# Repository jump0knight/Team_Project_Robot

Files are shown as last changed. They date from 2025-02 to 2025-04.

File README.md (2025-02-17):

# Robot Dog Project

Welcome to the **Robot Dog** project! This repository contains the design files and documentation for our ongoing team project, where we are creating a 3D-printed robot dog. We are integrating various components for functionality, such as sensors, motors, and body connections.

## Project Overview

The goal of this project is to design and build a **robot dog** capable of performing a range of tasks. Our team is working on several modules, including:

- **Body Structure**
- **Leg Connections**
- **Servo Motor Controls**
- **Sensor Integrations**

## Team Contributions

### Hasinu Ravishka
- Designed the **lower leg components** and integrated **servo motor mechanisms**, ensuring precise control over the robot's locomotion.
- Delivered key **mechanical designs** for the leg system, optimizing both **functionality** and **stability**.

### YanSheng Zhao
- Designed and sent the **Shoulder 3D Print**.
- Created and shared the **Wing 3D Print**, which plays a key role in enhancing the robot's **stability** and **movement**.

### Vladimir Galichyan
- Designed and shared the **Top Mount for Body-Sensor Connection** (STL files).
- Contributed to the overall **body** and **sensor** plots design, ensuring proper alignment for seamless connections between components.

### MingYu Xia
- Designed the **Leg-Connect** (now renamed to **Robot-Dog-Connection**), facilitating the connection between the leg components and the robot's body.
- Contributed to the **renaming** of the leg connection part for clarity and consistency.

## 3D Models and Design Files

Here, you will find various **STL** files for the robot's parts, designed for 3D printing:

- **Top Mount (Body-Sensor Connection)** – Essential for connecting the body and sensor components.
- **Shoulder 3D Print** – Part of the robot’s limb system, enabling movement and articulation.
- **Wing 3D Print** – Contributes to the robot's **stability** and overall **movement control**.
- **Lower Leg Design** – Includes 3D-printed parts for the lower leg, as well as **servo motor placement**.
- **Robot-Dog-Connection** – The connection mechanism between the robot's legs and body.

## How to Use

### Requirements:
- A **3D printer** capable of printing the provided **STL files**.
- A **servo motor** for controlling movement.
- A **compatible sensor** for integration with the robot's body.

### Steps:
1. **Download** the required STL files from this repository.
2. Use a **3D printer** to print the parts.
3. **Assemble** the robot following the provided designs and instructions for each module.
4. **Integrate** the motors and sensors as needed to bring the robot to life.

## Contributors
- **YanSheng Zhao**
- **Hasinu Ravishka**
- **Vladimir Galichyan**
- **MingYu Xia**

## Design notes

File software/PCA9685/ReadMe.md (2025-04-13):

# How to use these Library

## -------environment-------  Raspberry PI PICO ------ Mico Python

## First. Connect the PCA9685 

SCL - GPIO3

SDA - GPIO2

## Second. Put These three files in Pico



## Then. We make a main file to run the leg

```python
import leg
import math , time

print(leg.legleft1_A(90,160,120))
print(leg.legleft2_A(90,160,120))
print(leg.legright1_A(90,160,120))
print(leg.legright2_A(90,160,120))
```

## Final run  it you will see this data back . So it working.



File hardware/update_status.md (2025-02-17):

/******   2025 2 4  *******/

Create the task :

YanSheng Zhao -- shoulder and Wings design.

Hasinu Ravishka -- lower leg and servo motor design.

MingYu Xia -- leg-connect and sensor plots design.

Vladimir Galichyan -- body and sensor plots design.

/******************************************************/

/******   2025 2 11  *******/

/****** YanSheng Zhao ******/

Send the shoulder 3D print.

/****** Hasinu Ravishka******/

I have send lower leg and servo motor design.

/****** MingYu Xia******/

Send the leg-connect 3D print.

/******************************************************/

/******   2025 2 14  *******/

/****** YanSheng Zhao ******/

Send the Wing 3D print.

/****** MingYu  Xia ******/

I change the name from leg-connect to Robot-Dog-Connection

/****** Vladimir Galichyan ******/

Send top mount for body robot dog body-sensor connect stl

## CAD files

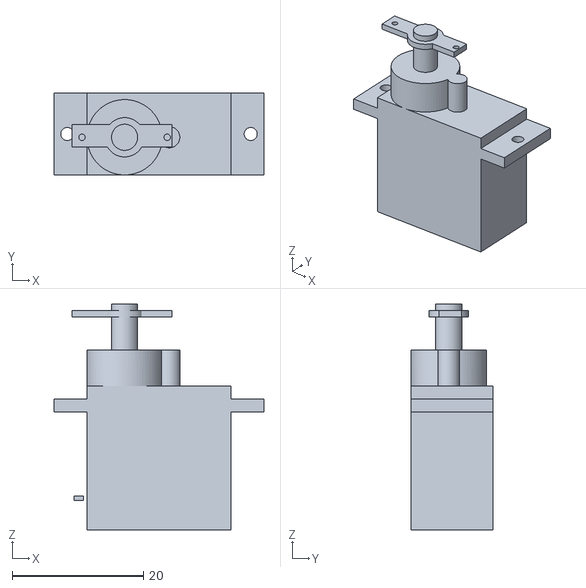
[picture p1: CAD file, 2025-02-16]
hardware/Robot-Dog- Servo.stl
32.0 x 12.5 x 34.5

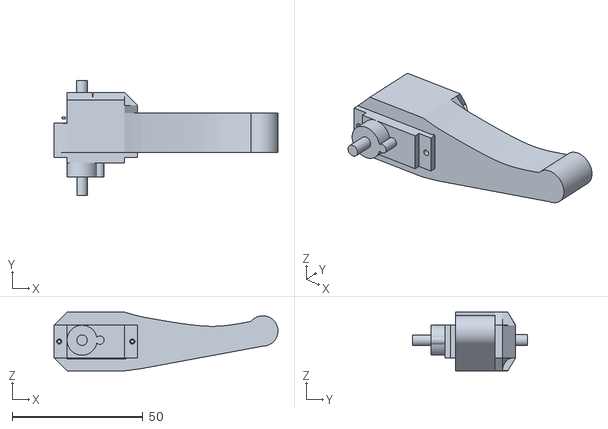
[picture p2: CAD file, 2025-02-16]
hardware/Robot-Dog-LowerLeg.stl
85.8 x 44.0 x 22.5

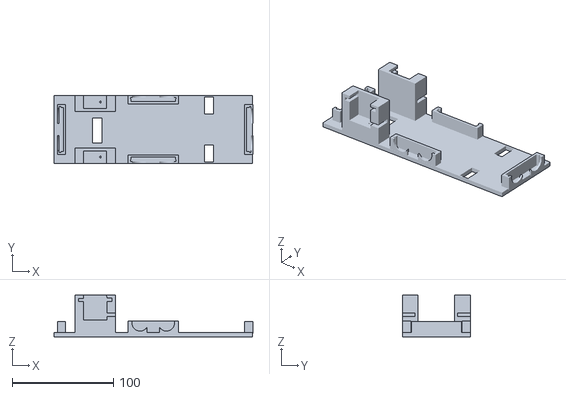
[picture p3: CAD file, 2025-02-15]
hardware/Robot-Dog-body-sensor connect.stl
196.7 x 67.3 x 41.1

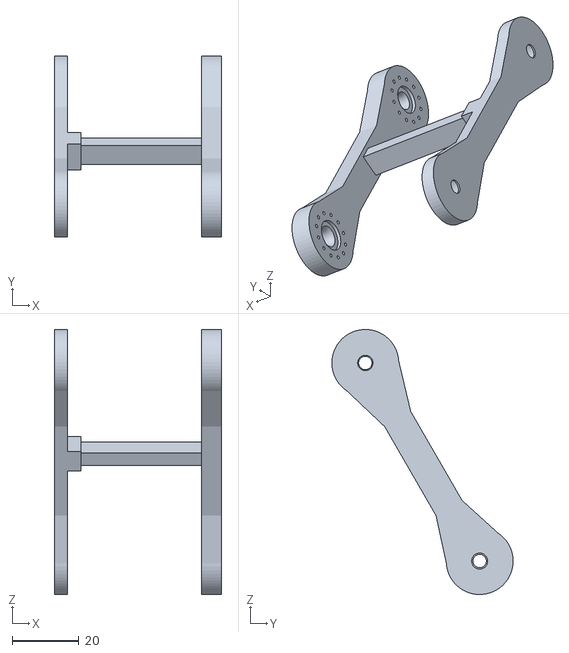
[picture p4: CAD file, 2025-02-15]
hardware/Robot-Dog-Connection.stl
50.0 x 54.2 x 79.1

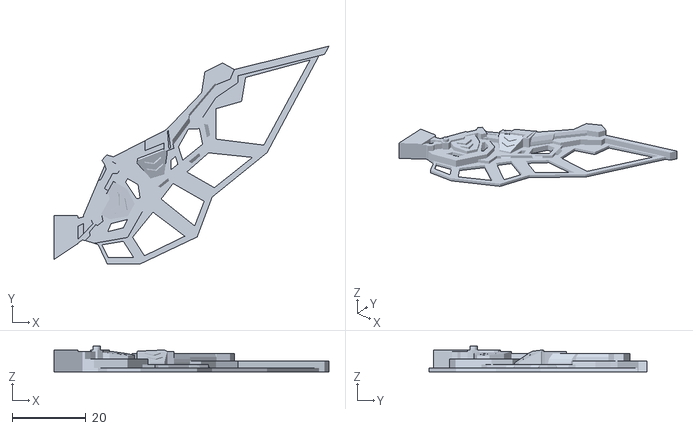
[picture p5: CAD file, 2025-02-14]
hardware/Robot-Dog-wing.stl
74.8 x 59.2 x 7.00

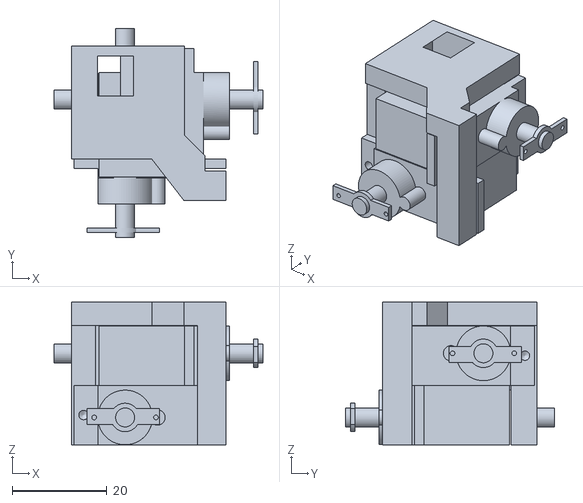
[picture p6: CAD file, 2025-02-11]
hardware/Robot-Dog-Shoulder.stl
44.0 x 44.0 x 30.0

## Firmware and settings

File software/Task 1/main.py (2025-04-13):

import machine
import time
import uasyncio as asyncio
import leg
import math
from machine import Pin, time_pulse_us

# UART 初始化
uart = machine.UART(1, baudrate=115200, tx=machine.Pin(4), rx=machine.Pin(5))

# 帧常量
HEADER1 = 0xFF
HEADER2 = 0xAA
FOOTER1 = 0xBF
FOOTER2 = 0xC0

# 全局状态
current_mode = "stop"

# ------------------------------
# 超声波传感器配置（根据实际接线修改引脚）
sensor1 = {
    'trig': Pin(16, Pin.OUT),
    'echo': Pin(17, Pin.IN),
    'name': 'Ultrasonic1'
}

sensor2 = {
    'trig': Pin(14, Pin.OUT),
    'echo': Pin(15, Pin.IN),
    'name': 'Ultrasonic2'
}

# ------------------------------
# 异步读取超声波传感器数据
async def read_ultrasonic(sensor):
    trig_pin = sensor['trig']
    echo_pin = sensor['echo']
    name = sensor['name']
    while True:
        # 发出触发脉冲
        trig_pin.value(0)
        time.sleep_us(2)
        trig_pin.value(1)
        time.sleep_us(10)
        trig_pin.value(0)
        try:
            pulse_time = time_pulse_us(echo_pin, 1, 1000000)
            # 计算距离（cm）：距离 = (脉冲时长/2) / 29.1
            distance = (pulse_time / 2) / 29.1
            if distance < 500:
                print(f"{name} Distance: {distance:.2f} cm")
        except OSError as e:
            print(f"{name} Ultrasonic Read Error:", e)
        await asyncio.sleep(0.5)

# ---------------- 参数 ----------------
step_period = 1000
base_hip = 160
base_knee = 120
base_shoulder = 90
amplitude_knee = 10
phase_offset_left1 = 0
phase_offset_left2 = math.pi
phase_offset_right1 = math.pi
phase_offset_right2 = 0

# ---------------- 运动函数 ----------------
def move_legs(amp_l, amp_r, dir_l=True, dir_r=True):
    current_time = time.ticks_ms()
    cycle_time = (current_time % step_period) / step_period
    phase = cycle_time * 2 * math.pi

    sign_l = 1 if dir_l else -1
    hip_left1 = base_hip + sign_l * amp_l * math.cos(phase + phase_offset_left1)
    knee_left1 = base_knee + amplitude_knee * math.sin(phase + phase_offset_left1)
    hip_left2 = base_hip + sign_l * amp_l * math.cos(phase + phase_offset_left2)
    knee_left2 = base_knee + amplitude_knee * math.sin(phase + phase_offset_left2)

    sign_r = 1 if dir_r else -1
    hip_right1 = base_hip + sign_r * amp_r * math.cos(phase + phase_offset_right1)
    knee_right1 = base_knee + amplitude_knee * math.sin(phase + phase_offset_right1)
    hip_right2 = base_hip + sign_r * amp_r * math.cos(phase + phase_offset_right2)
    knee_right2 = base_knee + amplitude_knee * math.sin(phase + phase_offset_right2)

    leg.legleft1_A(base_shoulder, hip_left1, knee_left1)
    leg.legleft2_A(base_shoulder, hip_left2, knee_left2)
    leg.legright1_A(base_shoulder, hip_right1, knee_right1)
    leg.legright2_A(base_shoulder, hip_right2, knee_right2)

def walk_forward():
    move_legs(10, 10, dir_l=True, dir_r=True)

def walk_backward():
    move_legs(10, 10, dir_l=False, dir_r=False)

def turn_left():
    move_legs(10, 10, dir_l=False, dir_r=True)

def turn_right():
    move_legs(10, 10, dir_l=True, dir_r=False)

def standstill():
    leg.legleft1_A(base_shoulder, base_hip, base_knee)
    leg.legleft2_A(base_shoulder, base_hip, base_knee)
    leg.legright1_A(base_shoulder, base_hip, base_knee)
    leg.legright2_A(base_shoulder, base_hip, base_knee)

# ---------------- 异步UART读取任务 ----------------
async def read_uart_loop():
    global current_mode

    while True:
        if uart.any():
            data = uart.read()
            if data and len(data) >= 12:
                if data[0] == HEADER1 and data[1] == HEADER2 and data[-2] == FOOTER1 and data[-1] == FOOTER2:
                    mode = data[2]
                    data_section = data[3:11]  # 取中间8字节

                    if len(data_section) == 8:
                        print("Mode:", mode)
                        print("Joystick data:", ', '.join(str(b) for b in data_section))

                        x = data_section[2]
                        y = data_section[1]

                        if y > 200:
                            current_mode = "forward"
                        elif y < 100:
                            current_mode = "backward"
                        elif x > 200:
                            current_mode = "left"
                        elif x < 100:
                            current_mode = "right"
                        else:
                            current_mode = "stop"
        await asyncio.sleep(0.02)  # 异步延迟10ms

# ---------------- 异步运动控制任务 ----------------
async def control_loop():
    while True:
        if current_mode == "forward":
            walk_forward()
        elif current_mode == "backward":
            walk_backward()
        elif current_mode == "left":
            turn_left()
        elif current_mode == "right":
            turn_right()
        else:
            standstill()
        print(current_mode)
        await asyncio.sleep(0.05)  # 控制节奏

# ---------------- 主入口 ----------------
async def main():
    asyncio.create_task(read_uart_loop())
    asyncio.create_task(control_loop())
    # 可在这里加其他任务，如超声波
    asyncio.create_task(read_ultrasonic(sensor1))
    asyncio.create_task(read_ultrasonic(sensor2))

    while True:
        
        await asyncio.sleep(0)

# 启动事件循环
asyncio.run(main())

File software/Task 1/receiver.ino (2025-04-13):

#include <Arduino.h>
#include <esp_now.h>
#include <WiFi.h>

// 目标设备的 MAC 地址
uint8_t broadcastAddress[] = {0xf0, 0xf5, 0xbd, 0x19, 0xa2, 0x30};  
int mode = 0; 
byte receive_data[8];

// 发送的数据结构
typedef struct struct_message
{
  byte header1;      // 帧头第一字节 0xFF
  byte header2;      // 帧头第二字节 0xAA
  byte mode;         // 模式选择位
  byte data[8];      // 数据部分，最大 8 字节
  byte footer1;      // 帧尾第一字节 0xBF
  byte footer2;      // 帧尾第二字节 0xC0
} struct_message;

struct_message myData;
esp_now_peer_info_t peerInfo;
struct_message receivedData;  // 在全局范围内定义接收数据的结构体

// 发送数据回调函数
void OnDataSent(const uint8_t *mac_addr, esp_now_send_status_t status)
{
    Serial.print("Last Packet Send Status: ");
    Serial.println(status == ESP_NOW_SEND_SUCCESS ? "Delivery Success" : "Delivery Fail");
}

// 接收数据回调函数
void OnDataReceived(const esp_now_recv_info_t *info, const uint8_t *data, int len) {
    // 将接收到的数据复制到结构体中
    memcpy(&receivedData, data, sizeof(receivedData));

    // 校验帧头和帧尾是否正确
    if (receivedData.header1 == 0xFF && receivedData.header2 == 0xAA && receivedData.footer1 == 0xBF && receivedData.footer2 == 0xC0) {
        // 打印接收到的数据
        mode = receivedData.mode;
        Serial.println("Data received:");

        // 重新打包数据并通过串口发送
        for (int i = 0; i < sizeof(receivedData.data); i++) {
            receive_data[i] = receivedData.data[i];
        }
        
        // 重新打包数据帧头、模式、数据和帧尾
        struct_message sendData;
        sendData.header1 = 0xFF;
        sendData.header2 = 0xAA;
        sendData.mode = receivedData.mode;  // 使用接收到的模式
        memcpy(sendData.data, receivedData.data, sizeof(receivedData.data));  // 使用接收到的数据
        sendData.footer1 = 0xBF;
        sendData.footer2 = 0xC0;

        // 将重新打包的数据通过串口1发送出去（TX = GPIO43, RX = GPIO44）
        Serial1.write((uint8_t*)&sendData, sizeof(sendData));
        Serial.println("Sent data via Serial1:");

        // 打印发送的数据
        for (int i = 0; i < sizeof(sendData.data); i++) {
            Serial.printf("Sending data %d: 0x%02X\n", i + 1, sendData.data[i]);
        }
    }
}

void setup()
{
    Serial.begin(115200);  // 使用默认串口与PC通信
    // 使用串口1，TX = GPIO43，RX = GPIO44
    Serial1.begin(115200, SERIAL_8N1, 43, 44);  

    WiFi.mode(WIFI_STA);  // 设置为 Station 模式

    if (esp_now_init() != ESP_OK)
    {
        Serial.println("Error initializing ESP-NOW");
        return;
    }

    esp_now_register_send_cb(OnDataSent);  // 注册发送数据的回调函数
    esp_now_register_recv_cb(OnDataReceived);  // 注册接收数据的回调函数

    // 配置目标设备的 MAC 地址
    memcpy(peerInfo.peer_addr, broadcastAddress, 6);
    peerInfo.channel = 0;  // 使用当前打开的通道
    peerInfo.encrypt = false;  // 不使用加密

    // 添加 peer
    if (esp_now_add_peer(&peerInfo) != ESP_OK)
    {
        Serial.println("Failed to add peer");
        return;
    }
}

// 数据处理函数
void Data_process(struct_message *myData, int mode_ch, byte *data, int dataLength) {
    myData->header1 = 0xFF;
    myData->header2 = 0xAA;
    myData->footer1 = 0xBF;
    myData->footer2 = 0xC0;

    myData->mode = mode_ch;

    // 填充数据部分
    for (int i = 0; i < dataLength && i < sizeof(myData->data); i++) {
        myData->data[i] = data[i];
    }
}

byte Data[] = {0x01, 0x02, 0x03, 0x04, 0x05, 0x06};

void loop()
{
    // 调用数据处理函数，传递结构体、模式选择位和数据
    Data_process(&myData, 0x01, Data, sizeof(Data));

    // 发送数据
    esp_err_t result = esp_now_send(broadcastAddress, (uint8_t *)&myData, sizeof(myData));  // 发送数据

    if (result == ESP_OK)
    {
        Serial.println("Sent with success");
    }
    else
    {
        Serial.println("Error sending the data");
    }
}

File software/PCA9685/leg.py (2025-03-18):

import math
from servo import Servos
from machine import Pin, I2C

i2c = I2C(1, scl=Pin(3), sda=Pin(2), freq=10000)

# 初始化 Servos 对象，指定 PCA9685 地址（默认为 0x40）
s = Servos(i2c, address=0x40)

class LegComponent:
    def __init__(self, sh=None, l1=None, l2=None):
        self.sh = sh
        self.l1 = l1
        self.l2 = l2

    def __repr__(self):
        return f"( sh={self.sh}, l1={self.l1}, l2={self.l2} )"


class Leg:
    def __init__(self):
        # 初始化四个部分
        self.leg_l1 = LegComponent()
        self.leg_l2 = LegComponent()
        self.leg_r1 = LegComponent()
        self.leg_r2 = LegComponent()

    def __repr__(self):
        return (f"leg_l1:{self.leg_l1}\n"
                f"leg_l2:{self.leg_l2}\n"
                f"leg_r1:{self.leg_r1}\n"
                f"leg_r2:{self.leg_r2}\n")

leg = Leg()

leg.leg_l1.sh = (2,145)
leg.leg_l1.l1 = (3,140)
leg.leg_l1.l2 = (6,90)

leg.leg_l2.sh = (8,120)
leg.leg_l2.l1 = (9,140)
leg.leg_l2.l2 = (14,90)

leg.leg_r1.sh = (1,85)
leg.leg_r1.l1 = (0,40)
leg.leg_r1.l2 = (7,100)

leg.leg_r2.sh = (5,135)
leg.leg_r2.l1 = (4,40)
leg.leg_r2.l2 = (15,85)

lz = 0.00
lz1 = 0.00
lz2 = 0.00
lx = 0.00
ly = 0.00
hu = 7.0
hl = 7.8
h = 0

def legleft1_A(data_y, data_a, data_b):
    s.position(leg.leg_l1.sh[0], data_y)  # s1
    s.position(leg.leg_l1.l1[0], data_a - 8)  # l1
    s.position(leg.leg_l1.l2[0], data_b + 5)  # l2
    
    rad_y = (data_y - 149) * (math.pi / 180)
    rad_a = (data_a - 90) * (math.pi / 180)
    rad_b = data_b * (math.pi / 180)
    rad_th = (math.pi/2 + rad_b - rad_a)
    lz = h * math.sin(rad_y) + (hu * math.cos(rad_a) + hl * math.sin(rad_th)) * math.cos(rad_y)
    ly = h * math.cos(rad_y) + (hu * math.cos(rad_a) + hl * math.sin(rad_th)) * math.sin(rad_y)
    lz1 = hu * math.cos(rad_a)
    lz2 = hl * math.sin(rad_th)
    lx = - (hu * math.sin(rad_a) + hl * math.cos(rad_th))
    return {"lx": lx, "lz": lz , "ly": ly , "a": data_a, "b": data_b , "y": rad_y}

def legleft2_A(data_y, data_a, data_b):
    s.position(leg.leg_l2.sh[0], data_y)  # s1
    s.position(leg.leg_l2.l1[0], data_a)  # l1
    s.position(leg.leg_l2.l2[0], data_b)  # l2
    
    rad_y = (data_y - 125) * (math.pi / 180)
    rad_a = (data_a - 90) * (math.pi / 180)
    rad_b = data_b * (math.pi / 180)
    rad_th = (math.pi/2 + rad_b - rad_a)
    lz = h * math.sin(rad_y) + (hu * math.cos(rad_a) + hl * math.sin(rad_th)) * math.cos(rad_y)
    ly = h * math.cos(rad_y) + (hu * math.cos(rad_a) + hl * math.sin(rad_th)) * math.sin(rad_y)
    lz1 = hu * math.cos(rad_a)
    lz2 = hl * math.sin(rad_th)
    lx = - (hu * math.sin(rad_a) + hl * math.cos(rad_th))
    return {"lx": lx, "lz": lz , "ly": ly , "a": data_a, "b": data_b , "y": rad_y}

def legright1_A(data_y, data_a, data_b):
    s.position(leg.leg_r1.sh[0], data_y)  # s1
    s.position(leg.leg_r1.l1[0], 180 - data_a)  # l1
    s.position(leg.leg_r1.l2[0], 180 - data_b)  # l2
    
    rad_y = (data_y - 90) * (math.pi / 180)
    rad_a = (data_a - 90) * (math.pi / 180)
    rad_b = data_b * (math.pi / 180)
    rad_th = (math.pi/2 + rad_b - rad_a)
    lz = h * math.sin(rad_y) + (hu * math.cos(rad_a) + hl * math.sin(rad_th)) * math.cos(rad_y)
    ly = -(h * math.cos(rad_y) + (hu * math.cos(rad_a) + hl * math.sin(rad_th)) * math.sin(rad_y))
    lz1 = hu * math.cos(rad_a)
    lz2 = hl * math.sin(rad_th)
    lx = - (hu * math.sin(rad_a) + hl * math.cos(rad_th))
    return {"lx": lx, "lz": lz , "ly": ly , "a": data_a, "b": data_b , "y": rad_y}

def legright2_A(data_y, data_a, data_b):
    s.position(leg.leg_r2.sh[0], data_y)  # s1
    s.position(leg.leg_r2.l1[0], 180 - data_a)  # l1
    s.position(leg.leg_r2.l2[0], 180 - data_b - 8)  # l2
    
    rad_y = (data_y - 135) * (math.pi / 180)
    rad_a = (data_a - 90) * (math.pi / 180)
    rad_b = data_b * (math.pi / 180)
    rad_th = (math.pi/2 + rad_b - rad_a)
    lz = h * math.sin(rad_y) + (hu * math.cos(rad_a) + hl * math.sin(rad_th)) * math.cos(rad_y)
    ly = -(h * math.cos(rad_y) + (hu * math.cos(rad_a) + hl * math.sin(rad_th)) * math.sin(rad_y))
    lz1 = hu * math.cos(rad_a)
    lz2 = hl * math.sin(rad_th)
    lx = - (hu * math.sin(rad_a) + hl * math.cos(rad_th))
    return {"lx": lx, "lz": lz , "ly": ly , "a": data_a, "b": data_b , "y": rad_y}

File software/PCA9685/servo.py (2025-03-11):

from pca9685 import PCA9685
import math

# ---------------------------
# Servos 类定义
# ---------------------------
class Servos:
    def __init__(self, i2c, address=0x40, freq=50, min_us=600, max_us=2400, degrees=180):
        self.period = 1000000 / freq
        self.min_duty = self._us2duty(min_us)
        self.max_duty = self._us2duty(max_us)
        self.degrees = degrees
        self.freq = freq
        self.pca9685 = PCA9685(i2c, address)
        self.pca9685.freq(freq)

    def _us2duty(self, value):
        return int(4095 * value / self.period)

    def position(self, index, degrees=None, radians=None, us=None, duty=None):
        span = self.max_duty - self.min_duty
        if degrees is not None:
            duty = self.min_duty + span * degrees / self.degrees
        elif radians is not None:
            duty = self.min_duty + span * radians / math.radians(self.degrees)
        elif us is not None:
            duty = self._us2duty(us)
        elif duty is not None:
            pass
        else:
            return self.pca9685.duty(index)
        duty = min(self.max_duty, max(self.min_duty, int(duty)))
        self.pca9685.duty(index, duty)

    def release(self, index):
        self.pca9685.duty(index, 0)

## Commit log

2025-01-31 Create CAD Designs
2025-02-04 Update CAD Designs
2025-02-08 lower leg
2025-02-10 Lower leg CAD Design
2025-02-11 Add files via upload
    A new structure, the right size for MF90, modernized joint width
    [Arm_1 v1.f3z, Lower_leg_v1_2 v2.f3z, ServoMF90 v1.f3d]
2025-02-11 lower leg design updated 1
2025-02-14 Rename wing v4.stl to Robot-Dog-wing.stl
    [Robot-Dog-wing.stl]
2025-02-14 Rename shoulder v1.stl to Robot-Dog-Shoulder.stl
    [Robot-Dog-Shoulder.stl]
2025-02-15 Rename Robot-Dog-xxx.stl to Robot-Dog-body-sensor connect.stl
    [Robot-Dog-body-sensorconnect.stl]
2025-02-15 Rename Robot-Dog-body-sensorconnect.stl to Robot-Dog-body-sensor connect.stl
    [Robot-Dog-body-sensor connect.stl]
2025-02-16 Robot-Dog- Lower-Leg.stl
    [Robot-Dog-LowerLeg.stl]
2025-03-11 Add files via upload
    Ultrasonic base code library.
2025-04-18 Light Sensor v2 + Ultrasonic Senor + Leg Control
2025-04-18 Create Light Sensor v2 + Ultrasonic Senor + Leg Control
2025-04-18 Update Light Sensor v2 + Ultrasonic Senor + Leg Control
